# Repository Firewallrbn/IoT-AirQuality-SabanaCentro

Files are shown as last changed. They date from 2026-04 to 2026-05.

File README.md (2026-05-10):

# Nodo Quetzal - Monitoreo de Calidad del Aire (Sabana Centro)










> **Sistema IoT de monitoreo ambiental de tres capas (Edge → Gateway → Cloud) desarrollado para la subregión de Sabana Centro, Colombia (aprox. 2.560 msnm).**

Este repositorio aloja el código fuente y la arquitectura completa de un sistema IoT que mide, almacena, analiza y visualiza en tiempo real la calidad del aire. El sistema combina un **Nodo Edge** (ESP32) con sensores ambientales, un **Gateway IoT** (Raspberry Pi 5) con base de datos SQLite y módulo de IA, y un **Dashboard Global** (Ubidots) accesible desde cualquier parte de Colombia — todo comunicado de extremo a extremo mediante el protocolo **MQTT**.

<div align="center">

 <!-- REFERENCIAS A IMAGENES DEL REPOSITORIO DE CÓDIGO (NO ELIMINAR) -->

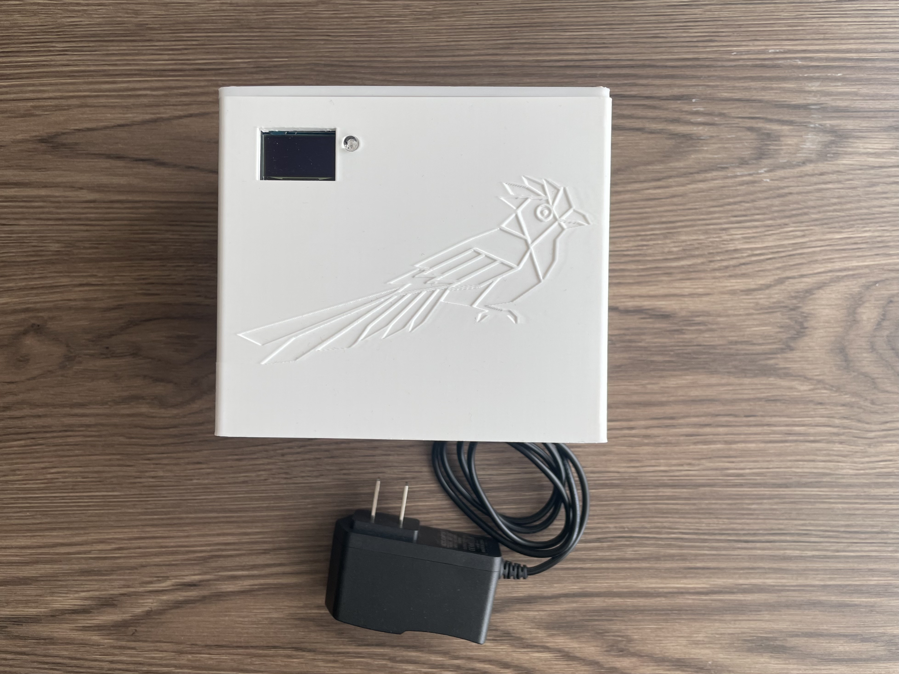
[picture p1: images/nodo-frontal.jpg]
Vista Frontal del Nodo
 

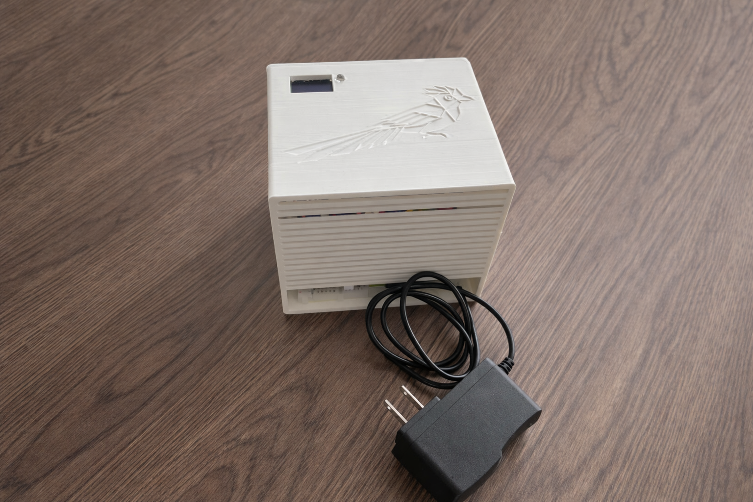
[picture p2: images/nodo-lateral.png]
Vista Lateral del Nodo
 

</div>

<br>

## Características Principales

* ** Procesamiento Edge Autónomo:** Basado en un microcontrolador ESP32 programado de manera nativa en C++ y gestionado usando PlatformIO. Incorpora algoritmos matemáticos como la compensación de temperatura y humedad κ-Köhler en el PMS5003 y un motor de reglas de fusión de datos de 5 matrices.

* ** Semaforización Normativa:** Lógica estricta de alertas basada en los límites de exposición permisibles de **OSHA y NIOSH**, alineados con la Resolución 2254 de 2017 del MinAmbiente y las Guías OMS 2021. Incluye notificación *in situ* con Matriz LED RGB y Buzzer.

* ** Doble Dashboard (Local + Global):** Servidor web embebido en el ESP32 para acceso local (WLAN), y Dashboard en Ubidots accesible desde cualquier navegador conectado a internet en Colombia.

* ** Comunicación MQTT End-to-End:** Protocolo MQTT asíncrono desde el ESP32 hasta Ubidots, pasando por un broker Mosquitto local en la Raspberry Pi. Elimina la latencia de HTTP y permite suscripciones bidireccionales.

* ** Persistencia Local Anti-Pérdidas:** Base de datos SQLite en la Raspberry Pi que almacena **todo** registro antes de enviarlo a la nube. Si se cae el internet, los datos quedan a salvo localmente.

* ** Inteligencia Artificial Integrada (Gemini 2.0 Flash):** Módulo autónomo que analiza las últimas lecturas y genera diagnósticos ambientales contextualizados. Se activa automáticamente cada 20 lecturas o manualmente desde el dashboard de Ubidots.

* ** Seguridad RBAC:** Control de Acceso Basado en Roles. El administrador genera URLs seguras de solo lectura para las autoridades (Rector, Alcaldía, CAR). Las credenciales sensibles residen exclusivamente en la Raspberry Pi.

* ** Tolerancia a Fallos Multicapa:** Reconexión automática en ESP32 (lógica `millis()` no bloqueante) y en el Gateway Python (`try-except` infinitos con reintentos cada 5 segundos). El sistema nunca se congela.

## Arquitectura de Hardware y Sensores

La solución integra múltiples niveles de detección, asegurando que la evaluación de la calidad del aire sea completa:

| Componente | Función Principal |
| :--- | :--- |
| **ESP32** | Cerebro de procesamiento Edge: bus I2C, ADC, UART, FreeRTOS dual-core, servidor web, cliente MQTT. |
| **Raspberry Pi 5** | Gateway IoT: Mosquitto broker, base de datos SQLite, puente MQTT a Ubidots, módulo de IA Gemini. |
| **PMS5003** | Sensor láser de dispersión para medición de material particulado PM2.5 atmosférico. |
| **MQ-135** | Detección de Gases nocivos y CO2. Calibración logarítmica ajustada dinámicamente. |
| **BMP280** | Medición de precisión barométrica, cambios de presión y altitud (Sabana Centro ~750 hPa). |
| **DHT22** | Muestreo en tiempo real de temperatura ambiental y humedad relativa. |
| **OLED SSD1306** | Display de interacción con el usuario final de 128x64 píxeles. |
| **LED RGB + Buzzer** | Actuadores de señalización de alertas directas y de rápida visualización a distancia. |

## Stack Tecnológico

| Capa | Tecnología | Lenguaje |
|---|---|---|
| **Firmware ESP32** | PlatformIO + Arduino Framework | C++ |
| **Gateway IoT** | Python 3 + paho-mqtt + SQLite | Python |
| **Broker MQTT** | Eclipse Mosquitto | — |
| **Cloud IoT** | Ubidots (MQTT + Dashboard) | — |
| **Inteligencia Artificial** | Google Gemini 2.0 Flash (API REST) | Python |
| **Base de Datos** | SQLite 3 (`historial_aire.db`) | SQL |

## Documentación Rigurosa (Wiki)

Debido a la magnitud de diseño, calibración, justificación de impacto en la zona de Sabana Centro, esquemáticos y validación metódica, **este repositorio cuenta con una extensa documentación ubicada en su WIKI oficial**.

Los invitamos profundamente a explorar cada una de las páginas, donde se hace desglose nivel experto del prototipo:

1. **[Resumen, Motivación y Solución Propuesta](https://github.com/Firewallrbn/IoT-AirQuality-SabanaCentro/wiki/1.-Resumen-General,-Motivación-y-Justificación)**: El encuadre del problema real en Cundinamarca y nuestro factor diferencial.

2. **[Arquitectura, Umbrales y Lógica de Fusión](https://github.com/Firewallrbn/IoT-AirQuality-SabanaCentro/wiki/2.-Solución-Propuesta)**: Diagramas UML, semaforización y motor de reglas multicapa.

3. **[Esquemáticos y Guía de Montaje Físico](https://github.com/Firewallrbn/IoT-AirQuality-SabanaCentro/wiki/2.5.-Montaje-Físico-y-Guía-de-Replicabilidad)**: Circuitería, esquemáticos CAD, y control de potencia.

4. **[Código Fuente del ESP32 Explicado](https://github.com/Firewallrbn/IoT-AirQuality-SabanaCentro/wiki/3.-Código-Fuente-Explicado)**: Walkthrough bloque por bloque del firmware con MQTT, FreeRTOS y servidor web.

5. **[Gateway IoT — Raspberry Pi](https://github.com/Firewallrbn/IoT-AirQuality-SabanaCentro/wiki/3.5.-Gateway-IoT-y-Código-del-Gateway-(Raspberry-Pi))**: Documentación completa del `gateway.py`: SQLite, doble cliente MQTT, módulo de IA Gemini.

6. **[Plataforma Cloud, Dashboard y Seguridad](https://github.com/Firewallrbn/IoT-AirQuality-SabanaCentro/wiki/4.5.-Plataforma-Cloud,-Dashboard-Global-y-Seguridad)**: Ubidots, acceso RBAC y cobertura local+global.

7. **[Resultados de Experimentación y Autoevaluación](https://github.com/Firewallrbn/IoT-AirQuality-SabanaCentro/wiki/5.-Configuración-Experimental,-Resultados-y-Análisis)**: Gráficas de medición, inyección de errores y análisis.

8. **[Protocolos de Uso, Replicabilidad y Video](https://github.com/Firewallrbn/IoT-AirQuality-SabanaCentro/wiki/7.-Protocolo-de-Replicabilidad)**: Instructivo completo para replicar el sistema de tres capas.

👉 **[HAZ CLIC AQUÍ PARA ACCEDER A LA WIKI DEL PROYECTO ACTUALIZADA](https://github.com/Firewallrbn/IoT-AirQuality-SabanaCentro/wiki)** 👈

---

## Equipo de Desarrollo e Investigación

Este prototipo hardware/software fue orquestado y creado por:

* **Juan David Cruz Angel** (@Firewallrbn) - Liderazgo de Hardware, Arquitectura Edge-to-Cloud, Firmware C++, Gateway Python e Integración IA.

* **Julián David Aguilar Zambrano** - Análisis de Integración, Investigación Científica y Pruebas Iniciales.

* **Alejandro Parra Galvis** - Project Management, Soporte de Visualizaciones y Documentación Estratégica.

<div align="center">

 <br>

 <i>Diseñado y ejecutado para el reto de Ingeniería IoT Avanzada — Universidad de la Sabana, 2026-1.</i>

</div>

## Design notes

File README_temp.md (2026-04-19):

# ðŸŒ Nodo IoT - Monitoreo de Calidad del Aire (Sabana Centro)






Â 

> **Prototipo de monitoreo ambiental *in situ* y de bajo costo desarrollado para la subregiÃ³n de Sabana Centro, Colombia (aprox. 2.560 msnm).**

Este repositorio aloja el cÃ³digo fuente y el diseÃ±o de la arquitectura de un sistema embebido experto, capaz de medir, analizar y fusionar en tiempo real la concentraciÃ³n de gases contaminantes, nivel de material particulado y variables meteorolÃ³gicas. El nodo ha sido diseÃ±ado para generar alertas tempranas visuales de manera autÃ³noma y local (sin conexiÃ³n a internet), aplicando los estÃ¡ndares de mediciÃ³n y semaforizaciÃ³n de salud ocupacional **OSHA y NIOSH**.

<div align="center">

Â  <!-- REFERENCIAS A IMAGENES DEL REPOSITORIO DE CÃ“DIGO (NO ELIMINAR) -->

Â  Vista Frontal del Nodo

Â  Vista Lateral del Nodo

</div>

Â 

<br>

Â 

## âœ¨ CaracterÃ­sticas Principales

* **ðŸ–¥ï¸ Procesamiento Edge AutÃ³nomo:** Basado en un microcontrolador ESP32 programado de manera nativa en C++ y gestionado usando PlatformIO. Incorpora algoritmos matemÃ¡ticos como la compensaciÃ³n de temperatura y humedad en el MQ-135.

* **ðŸš¦ SemaforizaciÃ³n Normativa:** LÃ³gica estricta de alertas basada en los lÃ­mites de exposiciÃ³n permisibles de **OSHA y NIOSH**. Cuenta con una Matriz LED RGB que emite notificaciones preventivas y crÃ­ticas de manera presencial.

* **ðŸ“Š VisualizaciÃ³n Local (HMI):** Interfaz implementada a travÃ©s de una pantalla OLED SSD1306, que permite consultar estados, promedios e indicaciones precisas en tiempo real directamente en el dispositivo.

* **ðŸŒ Tolerancia a Fallos Multicapa:** Protocolo de inyecciÃ³n de errores documentado. El dispositivo cuenta con un firmware capaz de discernir lecturas basura o desconexiones sin emitir falsas alarmas de contaminaciÃ³n.

## ðŸ› ï¸ Arquitectura de Hardware y Sensores

La soluciÃ³n integra mÃºltiples niveles de detecciÃ³n, asegurando que la evaluaciÃ³n de la calidad del aire sea completa:

| Componente | FunciÃ³n Principal |

| :--- | :--- |

| **ESP32** | Cerebro de procesamiento: bus I2C, lecturas analÃ³gicas, rutinas periÃ³dicas y matriz. |

| **MQ-135** | DetecciÃ³n de Gases nocivos y CO2. CalibraciÃ³n logarÃ­tmica ajustada dinÃ¡micamente. |

| **HW-870** | Monitoreo analÃ³gico de polvo y material particulado del entorno. |

| **BMP280** | MediciÃ³n de precisiÃ³n baromÃ©trica, cambios de presiÃ³n y altitud (Sabana Centro). |

| **DHT22** | Muestreo en tiempo real de temperatura ambiental y humedad relativa. |

| **OLED SSD1306** | Display de interacciÃ³n con el usuario final de 128x64. |

| **Matriz LED RGB**| Actuador de seÃ±alizaciÃ³n de alertas directas y de rÃ¡pida visualizaciÃ³n a la distancia. |

Â 

## ðŸ“– DocumentaciÃ³n Rigurosa (Wiki)

Debido a la magnitud de diseÃ±o, calibraciÃ³n, justificaciÃ³n de impacto en la zona de Sabana Centro, esquemÃ¡ticos y validaciÃ³n metÃ³dica, **este repositorio cuenta con una extensa documentaciÃ³n ubicada en su WIKI oficial**.

Los invitamos profundamente a explorar cada una de las pÃ¡ginas, donde se hace desglose nivel experto del prototipo:

1. **[Resumen, MotivaciÃ³n y SoluciÃ³n Propuesta]**: El encuadre del problema real en Cundinamarca y nuestro factor diferencial.

2. **[EsquemÃ¡ticos y GuÃ­a de Montaje FÃ­sico]**: ExplicaciÃ³n de circuiterÃ­a, esquemÃ¡ticos CAD, y control de potencia y hardware.

3. **[AnÃ¡lisis del CÃ³digo Fuente]**: Detalles profundos sobre las librerÃ­as, lÃ³gicas de interrupciÃ³n y unificaciÃ³n de las 3 fases del sensor.

4. **[Resultados de ExperimentaciÃ³n y AutoevaluaciÃ³n]**: GrÃ¡ficas de mediciÃ³n, anÃ¡lisis con inyecciÃ³n de errores, sensibilidad y casos de lÃ­mite experimental.

5. **[Protocolos de Uso, Replicabilidad y Video de ValidaciÃ³n]**: Instructivo detallado para escalar este proyecto a un sistema interconectado y los videos demostrativos del Ã©xito del nodo en laboratorio.

ðŸ‘‰ **[HAZ CLIC AQUÃ PARA ACCEDER A LA WIKI DEL PROYECTO ACTUALIZADA](#)** ðŸ‘ˆÂ Â 

*(Reemplaza "#" con el enlace real de la wiki de tu repositorio de Github/Gitlab).*

---

## ðŸ‘¨â€ðŸ’» Equipo de Desarrollo e InvestigaciÃ³n

Este prototipo hardware/software fue orquestado y creado por:

* **Juan David Cruz Angel** (@Firewallrbn) - Liderazgo de Hardware, Arquitectura LÃ³gica, CÃ³digo y SimulaciÃ³n.

* **JuliÃ¡n David Aguilar Zambrano** - AnÃ¡lisis de IntegraciÃ³n, InvestigaciÃ³n CientÃ­fica y Pruebas Iniciales.

* **Alejandro Parra Galvis** - Project Management, Soporte de Visualizaciones y DocumentaciÃ³n EstratÃ©gica.

<div align="center">

Â  <br>

Â  <i>DiseÃ±ado y ejecutado para el reto de IngenierÃ­a IoT Avanzada - 2026.</i>

</div>

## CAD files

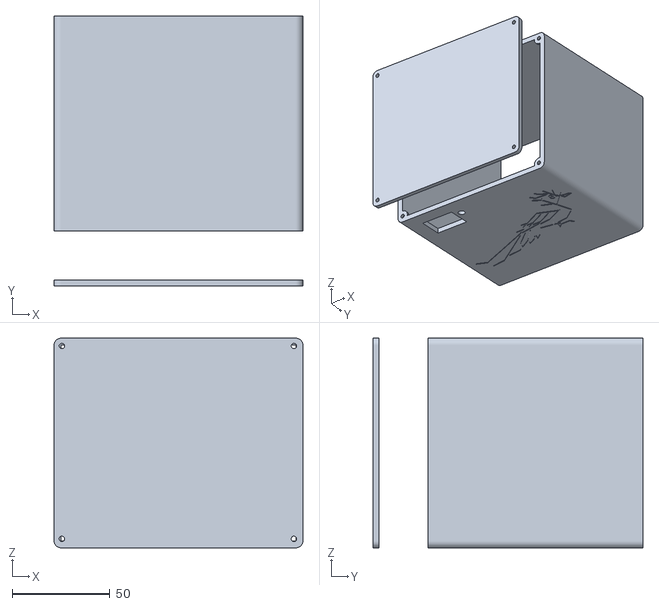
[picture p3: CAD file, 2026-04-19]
model3d/Nodo Quetzal IOT.stl
127.2 x 138.0 x 107.2

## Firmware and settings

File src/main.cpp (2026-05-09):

#include <Arduino.h>
#include <Wire.h>
#include <Adafruit_GFX.h>
#include <Adafruit_SSD1306.h>
#include <MQUnifiedsensor.h>
#include <Adafruit_Sensor.h>
#include <Adafruit_BMP280.h>
#include <DHT.h>
#include <WiFi.h>
#include <AsyncTCP.h>
#include <ESPAsyncWebServer.h>
#include <LittleFS.h>
#include <ArduinoJson.h>
#include <PubSubClient.h>

// =========================================================================
// CREDENCIALES WI-FI Y MQTT
// =========================================================================
const char* ssid     = "V2070";
const char* password = "12345678";

const char* mqtt_server = "172.20.10.2";
const int   mqtt_port   = 1883;
const char* mqtt_topic  = "sensor/datos";

// CAMBIO: client_id único evita colisiones si hay varios nodos en la red
const char* mqtt_client_id = "NodoQuetzal_ESP32_01";

WiFiClient   espClient;
PubSubClient mqttClient(espClient);

unsigned long ultimo_intento_mqtt = 0;
unsigned long ultimo_envio_mqtt   = 0;

AsyncWebServer server(80);

// =========================================================================
// PANTALLA OLED
// =========================================================================
#define SCREEN_WIDTH 128
#define SCREEN_HEIGHT 64
Adafruit_SSD1306 display(SCREEN_WIDTH, SCREEN_HEIGHT, &Wire, -1);

// =========================================================================
// PMS5003
// =========================================================================
#define PMS_RX_PIN 16
#define PMS_TX_PIN 17
#define PMS_SERIAL Serial2

// =========================================================================
// MQ-135
// =========================================================================
#define PIN_GAS            35
#define PLACA              "ESP-32"
#define VOLTAJE_RESOLUCION 3.3
#define ADC_BIT_RESOLUCION 12
#define TIPO_MQ            "MQ-135"
#define RATIO_AIRE_LIMPIO  3.6
MQUnifiedsensor MQ135(PLACA, VOLTAJE_RESOLUCION, ADC_BIT_RESOLUCION, PIN_GAS, TIPO_MQ);

// =========================================================================
// SENSORES CLIMÁTICOS
// =========================================================================
Adafruit_BMP280 bmp;
#define DHTPIN   4
#define DHTTYPE  DHT22
DHT dht(DHTPIN, DHTTYPE);

// =========================================================================
// ACTUADORES
// =========================================================================
#define PIN_ROJO   25
#define PIN_VERDE  26
#define PIN_AZUL   27
#define PIN_BUZZER 23

#define BUZZER_ON  LOW
#define BUZZER_OFF HIGH

// =========================================================================
// CONSTANTES FÍSICAS
// =========================================================================
const float KAPPA_PM        = 0.25;
const float M_FACTOR        = 0.85;
const float LIM_PM_MODERADO = 37.0;
const float LIM_VOC_CRITICO = 800.0;

// =========================================================================
// VARIABLES GLOBALES
// =========================================================================
volatile uint16_t pm25_value_crudo = 0;
volatile float    ppmGas   = 0.0;
volatile float    temp     = 0.0;
volatile float    presion  = 0.0;
volatile float    humedad  = 0.0;

float  pm25_corregido  = 0.0;
String estadoOLED      = "BUENA";
bool   alarma_silenciada = false;

float temp_historica = 0.0;
float pres_historica = 0.0;
unsigned long ultimo_guardado = 0;
bool  alerta_inversion = false;

#define MAX_HISTORIAL 30
float hist_pm[MAX_HISTORIAL];
float hist_gas[MAX_HISTORIAL];
unsigned long tiempo_ultimo_historial = 0;

SemaphoreHandle_t mutexI2C;

// =========================================================================
// FUNCIONES AUXILIARES
// =========================================================================
void setLEDColor(int r, int g, int b) {
  analogWrite(PIN_ROJO,  r);
  analogWrite(PIN_VERDE, g);
  analogWrite(PIN_AZUL,  b);
}

void sonarBuzzer(int tiempo) {
  if (!alarma_silenciada) {
    digitalWrite(PIN_BUZZER, BUZZER_ON);
    delay(tiempo);
    digitalWrite(PIN_BUZZER, BUZZER_OFF);
  } else {
    delay(tiempo);
  }
}

bool verifyChecksum(uint8_t* frame, uint16_t length) {
  uint16_t checksum = 0;
  for (int i = 0; i < length - 2; i++) checksum += frame[i];
  uint16_t received = (frame[length-2] << 8) | frame[length-1];
  return checksum == received;
}

void leerLaser() {
  static uint8_t buffer[128];
  static int idx = 0;
  while (PMS_SERIAL.available()) {
    buffer[idx] = PMS_SERIAL.read();
    if (idx >= 31) {
      for (int start = 0; start <= idx - 31; start++) {
        if (buffer[start] == 0x42 && buffer[start+1] == 0x4D) {
          uint16_t frame_len = (buffer[start+2] << 8) | buffer[start+3];
          int total_len = frame_len + 4;
          if (idx - start + 1 >= total_len) {
            if (verifyChecksum(&buffer[start], total_len))
              pm25_value_crudo = (buffer[start+12] << 8) | buffer[start+13];
            int remaining = idx - start - total_len + 1;
            for (int i = 0; i <= remaining; i++)
              buffer[i] = buffer[start + total_len + i];
            idx = remaining;
            break;
          }
        }
      }
    }
    idx = (idx + 1) % 128;
  }
}

// =========================================================================
// HILO DE SENSORES (CORE 0)
// =========================================================================
void TareaSensores(void *pvParameters) {
  for (;;) {
    leerLaser();
    MQ135.update();
    ppmGas  = MQ135.readSensor();
    humedad = dht.readHumidity();

    if (xSemaphoreTake(mutexI2C, portMAX_DELAY) == pdTRUE) {
      temp    = bmp.readTemperature();
      presion = bmp.readPressure() / 100.0F;
      xSemaphoreGive(mutexI2C);
    }
    vTaskDelay(pdMS_TO_TICKS(1000));
  }
}

// =========================================================================
// SETUP (CORE 1)
// =========================================================================
void setup() {
  delay(3000);
  Serial.begin(115200);
  Wire.begin();

  PMS_SERIAL.begin(9600, SERIAL_8N1, PMS_RX_PIN, PMS_TX_PIN);

  pinMode(PIN_ROJO,   OUTPUT);
  pinMode(PIN_VERDE,  OUTPUT);
  pinMode(PIN_AZUL,   OUTPUT);
  pinMode(PIN_BUZZER, OUTPUT);
  digitalWrite(PIN_BUZZER, BUZZER_OFF);
  setLEDColor(0, 0, 255);

  mutexI2C = xSemaphoreCreateMutex();

  if (!display.begin(SSD1306_SWITCHCAPVCC, 0x3C)) {
    Serial.println(F("Error OLED"));
    for (;;);
  }
  display.clearDisplay();
  display.setTextColor(SSD1306_WHITE);
  display.setTextSize(1);
  display.setCursor(0, 10); display.println(F("NODO QUETZAL"));
  display.println(F("Conectando Wi-Fi...")); display.display();

  if (!LittleFS.begin(true))
    Serial.println("Error montando LittleFS");

  WiFi.mode(WIFI_STA);
  WiFi.begin(ssid, password);
  int intentos = 0;
  while (WiFi.status() != WL_CONNECTED && intentos < 20) {
    delay(500); Serial.print(".");
    display.print("."); display.display();
    intentos++;
  }

  if (WiFi.status() == WL_CONNECTED) {
    Serial.println("\nWi-Fi Conectado!");
    mqttClient.setServer(mqtt_server, mqtt_port);

    display.clearDisplay();
    display.setTextSize(1); display.setCursor(20, 5);  display.println("--- WIFI OK ---");
    display.setCursor(0, 25); display.println("IP:");
    display.setTextSize(2); display.setCursor(0, 40);  display.println(WiFi.localIP());
    display.display();
    delay(5000);
    display.setTextSize(1);
  } else {
    display.clearDisplay();
    display.setCursor(0, 10); display.println("Fallo Wi-Fi.");
    display.display();
    delay(4000);
  }

  // --- Rutas del servidor web ---
  server.on("/", HTTP_GET, [](AsyncWebServerRequest *req){
    req->send(LittleFS, "/index.html", "text/html");
  });
  server.on("/style.css", HTTP_GET, [](AsyncWebServerRequest *req){
    req->send(LittleFS, "/style.css", "text/css");
  });
  server.on("/script.js", HTTP_GET, [](AsyncWebServerRequest *req){
    req->send(LittleFS, "/script.js", "application/javascript");
  });
  server.on("/datos", HTTP_GET, [](AsyncWebServerRequest *req){
    StaticJsonDocument<1024> doc;
    doc["pm25"]        = pm25_corregido;
    doc["gas"]         = ppmGas;
    doc["temp"]        = temp;
    doc["hum"]         = humedad;
    doc["pres"]        = presion;
    doc["estado"]      = estadoOLED;
    doc["alarma_mute"] = alarma_silenciada;

    JsonArray arr_pm  = doc.createNestedArray("historial_pm");
    JsonArray arr_gas = doc.createNestedArray("historial_gas");
    for (int i = 0; i < MAX_HISTORIAL; i++) {
      arr_pm.add(hist_pm[i]);
      arr_gas.add(hist_gas[i]);
    }
    String response;
    serializeJson(doc, response);
    req->send(200, "application/json", response);
  });
  server.on("/mute", HTTP_GET, [](AsyncWebServerRequest *req){
    alarma_silenciada = !alarma_silenciada;
    req->send(200, "text/plain", alarma_silenciada ? "Alarma Silenciada" : "Alarma Activada");
  });
  server.begin();

  // --- Sensores ---
  dht.begin();
  bmp.begin(0x76);
  MQ135.setRegressionMethod(1);
  MQ135.setA(110.47); MQ135.setB(-2.862);
  MQ135.init();

  float calcR0 = 0;
  for (int i = 1; i <= 10; i++) {
    MQ135.update();
    calcR0 += MQ135.calibrate(RATIO_AIRE_LIMPIO);
    sonarBuzzer(30); delay(200);
  }
  MQ135.setR0(calcR0 / 10);

  sonarBuzzer(100); delay(100); sonarBuzzer(300);
  setLEDColor(0, 0, 0);

  temp_historica = bmp.readTemperature();
  pres_historica = bmp.readPressure() / 100.0F;
  ultimo_guardado       = millis();
  tiempo_ultimo_historial = millis();

  for (int i = 0; i < MAX_HISTORIAL; i++) { hist_pm[i] = 0; hist_gas[i] = 0; }

  xTaskCreatePinnedToCore(TareaSensores, "Hilo_Sensores", 4096, NULL, 1, NULL, 0);
}

// =========================================================================
// LOOP PRINCIPAL (CORE 1)
// =========================================================================
void loop() {
  // --- Corrección PM2.5 por humedad ---
  if (humedad > 65.0) {
    float fc = 1.0 + (KAPPA_PM / ((100.0 / humedad) - 1.0));
    pm25_corregido = (pm25_value_crudo * M_FACTOR) / fc;
  } else {
    pm25_corregido = pm25_value_crudo * M_FACTOR;
  }

  // --- Actualizar historial cada 2 s ---
  if (millis() - tiempo_ultimo_historial > 2000) {
    for (int i = 0; i < MAX_HISTORIAL - 1; i++) {
      hist_pm[i]  = hist_pm[i+1];
      hist_gas[i] = hist_gas[i+1];
    }
    hist_pm[MAX_HISTORIAL - 1]  = pm25_corregido;
    hist_gas[MAX_HISTORIAL - 1] = ppmGas;
    tiempo_ultimo_historial = millis();
  }

  // --- Detección inversión térmica cada 10 s ---
  if (millis() - ultimo_guardado > 10000) {
    float dT = temp    - temp_historica;
    float dP = presion - pres_historica;
    alerta_inversion = (dT < -1.5 && temp < 12.0 && abs(dP) < 1.0);
    temp_historica = temp;
    pres_historica = presion;
    ultimo_guardado = millis();
  }

  // --- Lógica de alertas ---
  estadoOLED = "BUENA";
  setLEDColor(0, 255, 0);

  if (pm25_corregido > LIM_PM_MODERADO || ppmGas > LIM_VOC_CRITICO) {
    if (alerta_inversion && humedad > 80.0) {
      estadoOLED = "INV. TERMICA!";
      setLEDColor(255, 0, 0);
      sonarBuzzer(150); delay(150); sonarBuzzer(150);
    } else {
      estadoOLED = "POLUCION MIXTA";
      setLEDColor(255, 100, 0);
      sonarBuzzer(50); delay(100);
    }
  } else if (ppmGas > 1200.0) {
    estadoOLED = "FOCO CERCANO";
    setLEDColor(255, 0, 0);
    sonarBuzzer(300);
  } else if (pm25_corregido > LIM_PM_MODERADO) {
    estadoOLED = "POLVO REGIONAL";
    setLEDColor(255, 255, 0);
  } else if (pm25_value_crudo > 50 && pm25_corregido < 25) {
    estadoOLED = "NIEBLA PURA";
    setLEDColor(0, 255, 255);
  }

  // --- Pantalla OLED ---
  if (xSemaphoreTake(mutexI2C, portMAX_DELAY) == pdTRUE) {
    display.clearDisplay(); display.setTextSize(1);
    display.setCursor(20, 0); display.println(F("NODO QUETZAL"));
    display.drawLine(0, 10, 128, 10, SSD1306_WHITE);

    display.setCursor(0, 15);
    display.print(F("PM: ")); display.print(pm25_corregido, 1);
    display.setCursor(68, 15);
    display.print(F("T: ")); display.print(temp, 1); display.print(F("C"));

    display.setCursor(0, 28);
    display.print(F("Gas: ")); display.print(ppmGas, 0);
    display.setCursor(68, 28);
    display.print(F("H: ")); display.print(humedad, 1); display.print(F("%"));

    display.setCursor(0, 41);
    display.print(F("Presion: ")); display.print(presion, 0); display.print(F(" hPa"));

    display.drawLine(0, 52, 128, 52, SSD1306_WHITE);
    display.setCursor(0, 55);
    display.print(F("ST: ")); display.print(estadoOLED);
    if (alarma_silenciada) { display.setCursor(110, 55); display.print("[M]"); }

    display.display();
    xSemaphoreGive(mutexI2C);
  }

  // --- MQTT: reconexión y envío ---
  if (WiFi.status() == WL_CONNECTED) {
    if (!mqttClient.connected()) {
      if (millis() - ultimo_intento_mqtt > 5000) {
        Serial.print("Conectando MQTT...");
        if (mqttClient.connect(mqtt_client_id))
          Serial.println(" OK");
        else
          Serial.println(" Fallo. Reintentando.");
        ultimo_intento_mqtt = millis();
      }
    } else {
      mqttClient.loop();
    }

    if (mqttClient.connected() && millis() - ultimo_envio_mqtt > 5000) {
      StaticJsonDocument<200> docMQTT;
      docMQTT["pm25"]   = pm25_corregido;
      docMQTT["gas"]    = ppmGas;
      docMQTT["temp"]   = temp;
      docMQTT["hum"]    = humedad;
      docMQTT["pres"]   = presion;
      docMQTT["estado"] = estadoOLED;

      String jsonString;
      serializeJson(docMQTT, jsonString);
      mqttClient.publish(mqtt_topic, jsonString.c_str());
      Serial.println("MQTT -> RPi: " + jsonString);
      ultimo_envio_mqtt = millis();
    }
  }

  delay(1000);
}

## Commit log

2026-04-15 Implementacion del dashboard + Acualizacion de la logica
2026-04-19 readme + archivos
    [Nodo Quetzal IOT.stl]
